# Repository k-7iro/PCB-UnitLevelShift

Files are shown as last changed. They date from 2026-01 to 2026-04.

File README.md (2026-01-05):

# PCB-LogicShifterUnit
This logic level shifter has the same shape as the M5Stack Unit and can be used to connect the M5Stack Unit or M5Stack Controller (Core, Atom, etc) to an Arduino.

logicshifterunit

## Specification
The side marked "LV 3.3V" allows you to solder 2mm pitch 4-pin connectors. This includes Grove connectors and PH connectors. The signal voltage is 3.3V. Please note that the power supply voltage is 5V.

The side marked "HV 5V" allows you to solder 2.54mm pitch 4-pin connectors. This includes common pin headers and XH connectors. The signal voltage is 5V.

There is no specification for the direction of the power supply or signal. Signals are pulled up. Analog signals cannot be handled.

## Pinout Tips
| LV-Side Device | HV-Side A | HV-Side B |
| ---- | ---- | ---- |
| M5Stack Controller & Unit (I2C) | SDA | SCL |
| M5Stack Controller (UART) | LV:TxD HV:RxD *1 | LV:RxD HV:TxD *1 |
| M5Stack Unit (UART) | LV:RxD HV:TxD *1 | LV:TxD HV:RxD *1 |
| M5Stack Controller & Unit (GPIO) | *2 | *2 |

- *1: In the case of LV:TxD HV:RxD, connect the RxD pin of the Arduino or any microcontroller to HV-Side A, and vice versa.
- *2: For Controller, please check the your source code, and for Unit, please check the product page.

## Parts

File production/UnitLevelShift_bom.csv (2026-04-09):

Designator | Footprint | Quantity | Value | LCSC Part #
C1, C2 | 0402 | 2 | 1uF
D1 | LED_D3.0mm | 1 | LED
J1 | JST_PH_S4B-PH-K_1x04_P2.00mm_Horizontal | 1 | Conn_01x04_Pin
J2 | PinHeader_1x04_P2.54mm_Vertical | 1 | Conn_01x04_Pin
Q1, Q2 | SOT-23 | 2 | 2N7002
R1, R2, R3, R4 | 0402 | 4 | 4.7kΩ
R5 | R_Axial_DIN0204_L3.6mm_D1.6mm_P2.54mm_Vertical | 1 | 4.7kΩ
U1 | SOT-23-3 | 1 | XC6206PxxxMR

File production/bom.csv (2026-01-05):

Designator | Footprint | Quantity | Value | LCSC Part #
C1, C2 | 0402 | 2 | 1uF
D1 | 0603 | 1 | LED
J1 | JST_PH_S4B-PH-K_1x04_P2.00mm_Horizontal | 1 | Conn_01x04_Pin
J2 | PinHeader_1x04_P2.54mm_Vertical | 1 | Conn_01x04_Pin
Q1, Q2 | SOT-23 | 2 | 2N7002
R1, R2, R3, R4, R5 | 0402 | 5 | 4.7kΩ
U1 | SOT-23-3 | 1 | XC6206PxxxMR

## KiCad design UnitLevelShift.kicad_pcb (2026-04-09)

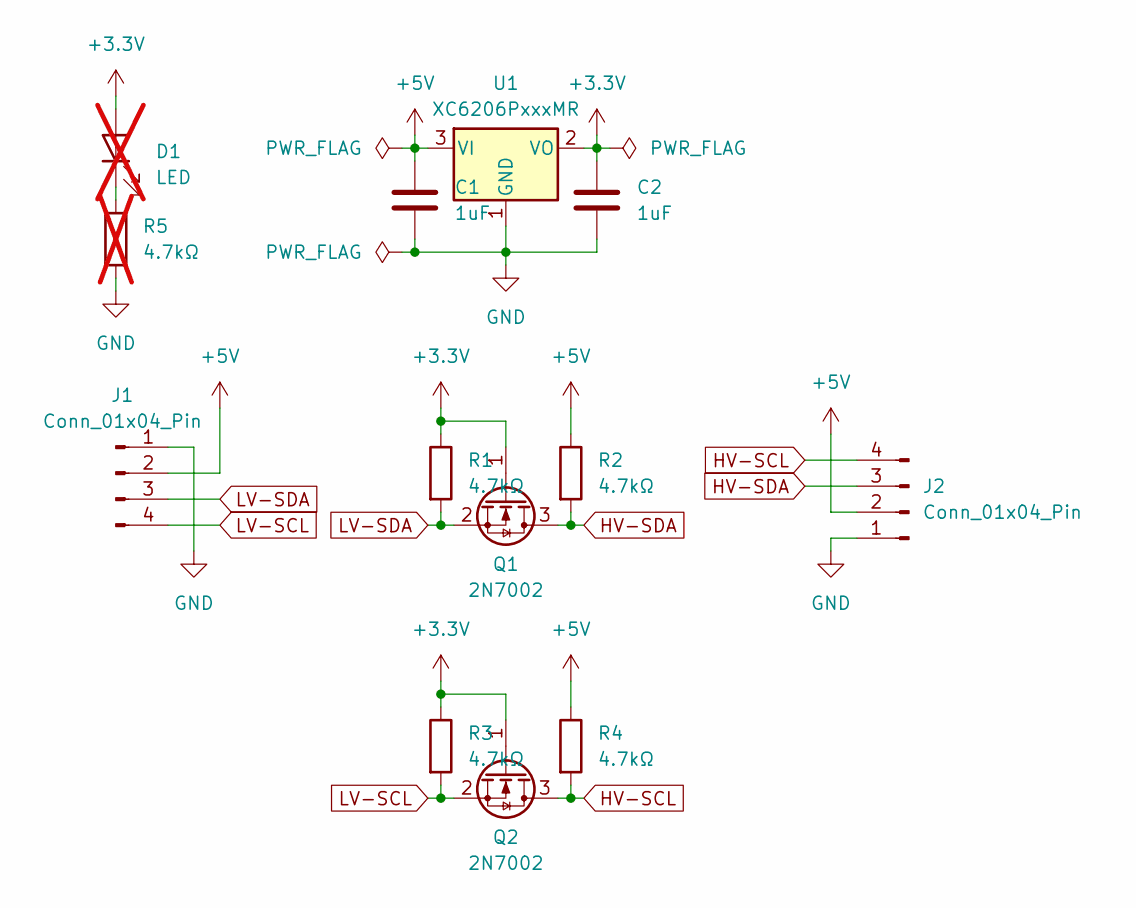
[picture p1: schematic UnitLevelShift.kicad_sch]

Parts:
C1, C2: 1uF; C_0402_1005Metric
D1: LED; LED_D3.0mm; not fitted
J1: Conn_01x04_Pin; JST_PH_S4B-PH-K_1x04_P2.00mm_Horizontal
J2: Conn_01x04_Pin; PinHeader_1x04_P2.54mm_Vertical
Q1, Q2: 2N7002; SOT-23
R1, R2, R3, R4: 4.7kΩ; R_0402_1005Metric
R5: 4.7kΩ; R_Axial_DIN0204_L3.6mm_D1.6mm_P2.54mm_Vertical; not fitted
U1: XC6206PxxxMR; SOT-23-3

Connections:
+3.3V: C2.1, D1.2 (A), Q1.1 (G), Q2.1 (G), R1.1, R3.1, U1.2 (VO)
+5V: C1.1, J1.2, J2.2, R2.1, R4.1, U1.3 (VI)
GND: C1.2, C2.2, J1.1, J2.1, R5.2, U1.1 (GND)
HV-SCL: J2.4, Q2.3 (D), R4.2
HV-SDA: J2.3, Q1.3 (D), R2.2
LV-SCL: J1.4, Q2.2 (S), R3.2
LV-SDA: J1.3, Q1.2 (S), R1.2
unnamed: D1.1 (K), R5.1

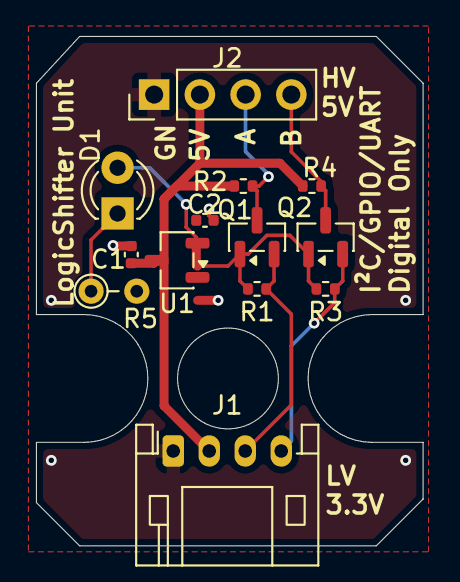
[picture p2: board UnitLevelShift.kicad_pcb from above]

Board: 2 copper layers, 21.5 x 28.3 mm, 13 parts (0 on the bottom side), 8 nets.

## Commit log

2026-01-05 Added V1 Schematics and PCB
    [UnitLevelShift.kicad_pcb, UnitLevelShift.kicad_sch, bom.csv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]
2026-01-05 Revise README for PCB-LogicShifterUnit details
    Updated the README to reflect the correct product name and added specifications and pinout tips.
2026-04-09 Changed LED to optional mounting.
    [UnitLevelShift.kicad_pcb, UnitLevelShift.kicad_sch, UnitLevelShift_bom.csv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]
